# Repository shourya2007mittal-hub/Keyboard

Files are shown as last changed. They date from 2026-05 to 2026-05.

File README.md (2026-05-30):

# KEYBOARD
So I am making an 60% layout keyboard with 2 rotor encoders .So In total there will be 61 Keys and 2 rotor encoders for volume and britness controle but there aren't that many gpios in any devboard therefore I would be using keyboard matrix and diodes to restrict gosting and I choosed Raspberry Pico as controller because it supports KMK and have enought Gpios as well.I also added stabalizers for any keys whose size is over 1.75U
## Features

- Base on Raspberry pico
- Has 61 keys ( 60% Keyboard Matrix)
- Has 2 Rotor Encoder
  ### Schematic
  br>

  ###  PCB Design
<br>


### 3D Design



- ## Bill of Materials (BOM)

| # | Item | Description | Quantity | Unit Price (USD) | Total (USD) | Link |
|---|---|---|---|---|---|---|
| 1 | 80Retros x HMX Volume | Mechanical switches (pack of 35) | 2 packs | 17.8 | 35.6 | https://stackskb.com/store/hmx-volume-0-pack-of-35/ |
| 2 | 1N4148 Diode | DO-35 switching diode | 61 | 0 | 0 | | Already have
| 3 | Raspberry Pi Pico H | RP2040 microcontroller board | 1 | 5.5 | 5.5 | https://robu.in/product/raspberry-pi-pico-with-headers/ |
| 4 |  Keycap Set | Full keycap set | 1 | 26.2 | 26.2 | https://stackskb.com/store/blue-and-blue-double-shot-abs-cherry-profile-keycaps-pre-order/
| 5 | Screw-In Stabilizers V2 | Keyboard stabilizers | 1 | 0 |0 | Already have |
| 6 | PCB  + Shipping | PCB fabrication (JLCPCB) | 1 |31.55| 31.55 | https://jlcpcb.com |

**Estimated Total Hardware Cost:** **USD 98.85**

## Hardware
- Raspberry Pico 
- Cherry MX compatible Switches
- Diode
- 2 layer PCB
- 2 Rotor Encoder

## Firmware
- It is Based on KMK and Circuit Python

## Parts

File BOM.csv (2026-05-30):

Index | Quantity | Part Number | Manufacturer Part Number | Description | Available | Unit Price | Extended Price USD | Link
1 | 2 (pack of 35) | 1644-MX2A-HC1B-ND | 80Retros x HMX Volume |  | 2 | 17.8 | 35.6 | https://stackskb.com/store/hmx-volume-0-pack-of-35/
2 | 61 | 1N4148FSCT-ND | 1N4148TR | DIODE STANDARD 100V 200MA DO35 | Already have | 0 | 0
3 | 1 | 2648-SC0917-ND | SC0917 | Raspberry Pi Pico H RP2040 | 1 | 5.5 | 5.5 | https://robu.in/product/raspberry-pi-pico-with-headers/
4 | 1 | Keycaps Set |  | Keycap Set |  | 26.2 | 26.2 | https://stackskb.com/store/blue-and-blue-double-shot-abs-cherry-profile-keycaps-pre-order/
5 | 1 | Stabilizer |  | 0Already Have |  | 0 | 0
6 | 1 | PCB + 3D Case + Shipping | JLCPCB | PCB fabrication and shipping |  | 31.55 | 31.55 | https://jlcpcb.com

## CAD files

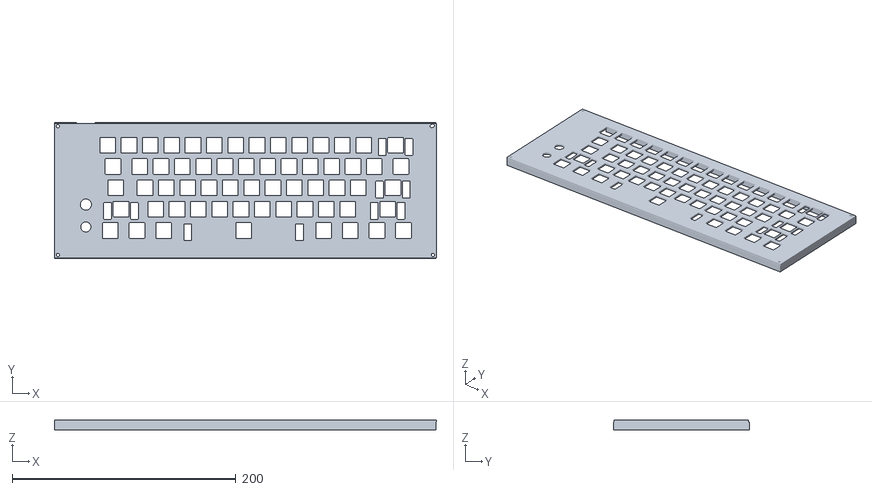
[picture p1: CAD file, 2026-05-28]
Production/UpCase.stl
341.2 x 121.1 x 9.00

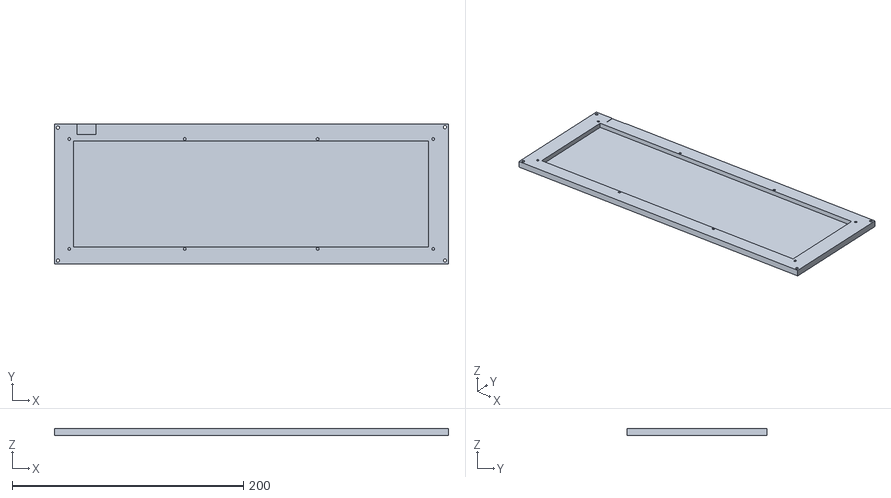
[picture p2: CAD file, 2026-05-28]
Production/LowCover.stl
341.0 x 121.0 x 6.20

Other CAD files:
CAD/Keyboard().f3d

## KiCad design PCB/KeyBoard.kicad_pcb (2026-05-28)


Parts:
A1: RaspberryPi_Pico; RaspberryPi_Pico_Common_Unspecified
D1, D2, D3, D4, D5, D6, D7, D8, D9, D10, D11, D12, D13, D14, D15, D16, D17, D18, D19, D20, D21, D22, D23, D24, D25, D26, D27, D28, D29, D30, D31, D32, D33, D34, D35, D36, D37, D38, D39, D40, D41, D42, D43, D44, D45, D46, D47, D48, D49, D50, D51, D52, D53, D54, D55, D56, D57, D58, D59, D60, D61: 1N4148; D_DO-35_SOD27_P7.62mm_Horizontal
S1: MX_stab; STAB_MX_2u
S2, S3: MX_stab; STAB_MX_2.25u
S4: MX_stab; STAB_MX_2.75u
S5: MX_stab; STAB_MX_6.25u
SW1, SW2, SW3, SW4, SW5, SW6, SW7, SW8, SW9, SW10, SW11, SW12, SW13, SW16, SW17, SW18, SW19, SW20, SW21, SW22, SW23, SW24, SW25, SW26, SW27, SW30, SW31, SW32, SW33, SW34, SW35, SW36, SW37, SW38, SW39, SW40, SW51, SW52, SW53, SW54, SW55, SW56, SW57, SW58, SW59, SW60: SW_Push; SW_Cherry_MX_1.00u_PCB
SW14: SW_Push; SW_Cherry_MX_2.00u_PCB
SW15: SW_Push; SW_Cherry_MX_1.50u_PCB
SW28: SW_Push; SW_Cherry_MX_1.50u_Plate
SW29: SW_Push; SW_Cherry_MX_1.75u_PCB
SW41, SW50: SW_Push; SW_Cherry_MX_2.25u_PCB
SW42, SW43, SW44, SW46, SW48, SW49: SW_Push; SW_Cherry_MX_1.25u_PCB
SW45: SW_Push; SW_Cherry_MX_6.25u_PCB
SW47: SW_Push; SW_Cherry_MX_1.25u_Plate
SW61: SW_Push; SW_Cherry_MX_2.75u_PCB
SW62, SW63: RotaryEncoder_Switch_MP; RotaryEncoder_Alps_EC11E-Switch_Vertical_H20mm

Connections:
A1: A1.27 (GPIO21), SW62.A
A2: A1.32 (GPIO27_ADC1), SW63.A
B1: A1.29 (GPIO22), SW62.B
B2: A1.34 (GPIO28_ADC2), SW63.B
C0: A1.10 (GPIO7), SW1.1, SW15.1, SW29.1, SW42.1, SW50.1
C1: A1.11 (GPIO8), SW2.1, SW16.1, SW30.1, SW43.1, SW51.1
C2: A1.12 (GPIO9), SW3.1, SW17.1, SW31.1, SW44.1, SW52.1
C3: A1.14 (GPIO10), SW4.1, SW18.1, SW32.1, SW53.1
C4: A1.15 (GPIO11), SW5.1, SW19.1, SW33.1, SW54.1
C5: A1.16 (GPIO12), SW6.1, SW20.1, SW34.1, SW45.1, SW55.1
C6: A1.17 (GPIO13), SW7.1, SW21.1, SW35.1, SW56.1
C7: A1.19 (GPIO14), SW8.1, SW22.1, SW36.1, SW57.1
C8: A1.20 (GPIO15), SW9.1, SW23.1, SW37.1, SW46.1, SW58.1
C9: A1.21 (GPIO16), SW10.1, SW24.1, SW38.1, SW47.1, SW59.1
C10: A1.22 (GPIO17), SW11.1, SW25.1, SW39.1, SW48.1, SW60.1
C11: A1.24 (GPIO18), SW12.1, SW26.1, SW40.1, SW49.1, SW61.1
C12: A1.25 (GPIO19), SW13.1, SW27.1, SW41.1
C13: A1.26 (GPIO20), SW14.1, SW28.1
GND: A1.33 (AGND), SW62.C, SW62.S2, SW63.C, SW63.S2
unnamed: A1.3 (GND), A1.8 (GND), A1.13 (GND), A1.18 (GND), A1.23 (GND), A1.28 (GND), A1.38 (GND)
unnamed: D1.2 (A), SW1.2
unnamed: D2.2 (A), SW2.2
unnamed: D3.2 (A), SW3.2
unnamed: D4.2 (A), SW4.2
unnamed: D5.2 (A), SW5.2
unnamed: D6.2 (A), SW6.2
unnamed: D7.2 (A), SW7.2
unnamed: D8.2 (A), SW8.2
unnamed: D9.2 (A), SW9.2
unnamed: D10.2 (A), SW10.2
unnamed: D11.2 (A), SW11.2
unnamed: D12.2 (A), SW12.2
unnamed: D13.2 (A), SW13.2
unnamed: D14.2 (A), SW14.2
unnamed: D15.2 (A), SW15.2
unnamed: D16.2 (A), SW16.2
unnamed: D17.2 (A), SW17.2
unnamed: D18.2 (A), SW18.2
unnamed: D19.2 (A), SW19.2
unnamed: D20.2 (A), SW20.2
unnamed: D21.2 (A), SW21.2
unnamed: D22.2 (A), SW22.2
unnamed: D23.2 (A), SW23.2
unnamed: D24.2 (A), SW24.2
unnamed: D25.2 (A), SW25.2
unnamed: D26.2 (A), SW26.2
unnamed: D27.2 (A), SW27.2
unnamed: D28.2 (A), SW28.2
unnamed: D29.2 (A), SW29.2
unnamed: D30.2 (A), SW30.2
unnamed: D31.2 (A), SW31.2
unnamed: D32.2 (A), SW32.2
unnamed: D33.2 (A), SW33.2
unnamed: D34.2 (A), SW34.2
unnamed: D35.2 (A), SW35.2
unnamed: D36.2 (A), SW36.2
unnamed: D37.2 (A), SW37.2
unnamed: D38.2 (A), SW38.2
unnamed: D39.2 (A), SW39.2
unnamed: D40.2 (A), SW40.2
unnamed: D41.2 (A), SW41.2
unnamed: D42.2 (A), SW42.2
unnamed: D43.2 (A), SW43.2
unnamed: D44.2 (A), SW44.2
unnamed: D45.2 (A), SW45.2
unnamed: D46.2 (A), SW46.2
unnamed: D47.2 (A), SW47.2
unnamed: D48.2 (A), SW48.2
unnamed: D49.2 (A), SW49.2
unnamed: D50.2 (A), SW50.2
unnamed: D51.2 (A), SW51.2
unnamed: D52.2 (A), SW52.2
unnamed: D53.2 (A), SW53.2
unnamed: D54.2 (A), SW54.2
unnamed: D55.2 (A), SW55.2
unnamed: D56.2 (A), SW56.2
unnamed: D57.2 (A), SW57.2
unnamed: D58.2 (A), SW58.2
unnamed: D59.2 (A), SW59.2
unnamed: D60.2 (A), SW60.2
unnamed: D61.2 (A), SW61.2
R0: A1.4 (GPIO2), D1.1 (K), D2.1 (K), D3.1 (K), D4.1 (K), D5.1 (K), D6.1 (K), D7.1 (K), D8.1 (K), D9.1 (K), D10.1 (K), D11.1 (K), D12.1 (K), D13.1 (K), D14.1 (K)
R1: A1.5 (GPIO3), D15.1 (K), D16.1 (K), D17.1 (K), D18.1 (K), D19.1 (K), D20.1 (K), D21.1 (K), D22.1 (K), D23.1 (K), D24.1 (K), D25.1 (K), D26.1 (K), D27.1 (K), D28.1 (K)
R2: A1.6 (GPIO4), D29.1 (K), D30.1 (K), D31.1 (K), D32.1 (K), D33.1 (K), D34.1 (K), D35.1 (K), D36.1 (K), D37.1 (K), D38.1 (K), D39.1 (K), D40.1 (K), D41.1 (K)
R3: A1.7 (GPIO5), D50.1 (K), D51.1 (K), D52.1 (K), D53.1 (K), D54.1 (K), D55.1 (K), D56.1 (K), D57.1 (K), D58.1 (K), D59.1 (K), D60.1 (K), D61.1 (K)
R4: A1.9 (GPIO6), D42.1 (K), D43.1 (K), D44.1 (K), D45.1 (K), D46.1 (K), D47.1 (K), D48.1 (K), D49.1 (K)
S1: A1.31 (GPIO26_ADC0), SW62.S1
S2: A1.2 (GPIO1), SW63.S1



Board: 2 copper layers, 321.0 x 101.0 mm, 130 parts (61 on the bottom side), 88 nets.

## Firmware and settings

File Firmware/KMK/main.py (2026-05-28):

import board
import digitalio
import usb_hid
import rotaryio
from adafruit_hid.keyboard import Keyboard
from adafruit_hid.keycode import Keycode
from adafruit_hid.consumer_control import ConsumerControl
from adafruit_hid.consumer_control_code import ConsumerControlCode
import time

kbd = Keyboard(usb_hid.devices)
cc = ConsumerControl(usb_hid.devices)

# =========================
# MATRIX SETUP
# =========================

ROW_PINS = [board.GP2, board.GP3, board.GP4, board.GP5, board.GP6]
COL_PINS = [
    board.GP7, board.GP8, board.GP9, board.GP10,
    board.GP11, board.GP12, board.GP13,
    board.GP14, board.GP15, board.GP16,
    board.GP17, board.GP18, board.GP19, board.GP20
]

rows = []
cols = []

for pin in ROW_PINS:
    r = digitalio.DigitalInOut(pin)
    r.direction = digitalio.Direction.OUTPUT
    r.value = True
    rows.append(r)

for pin in COL_PINS:
    c = digitalio.DigitalInOut(pin)
    c.direction = digitalio.Direction.INPUT
    c.pull = digitalio.Pull.UP
    cols.append(c)

# Example 60% partial keymap (edit fully yourself)
keymap = [
    [Keycode.ESCAPE, Keycode.ONE, Keycode.TWO, Keycode.THREE, Keycode.FOUR,
     Keycode.FIVE, Keycode.SIX, Keycode.SEVEN, Keycode.EIGHT,
     Keycode.NINE, Keycode.ZERO, Keycode.MINUS,
     Keycode.EQUALS, Keycode.BACKSPACE],

    [Keycode.TAB, Keycode.Q, Keycode.W, Keycode.E, Keycode.R,
     Keycode.T, Keycode.Y, Keycode.U, Keycode.I,
     Keycode.O, Keycode.P, Keycode.LEFT_BRACKET,
     Keycode.RIGHT_BRACKET, Keycode.BACKSLASH],

    [Keycode.CAPS_LOCK, Keycode.A, Keycode.S, Keycode.D, Keycode.F,
     Keycode.G, Keycode.H, Keycode.J, Keycode.K,
     Keycode.L, Keycode.SEMICOLON, Keycode.QUOTE,
     Keycode.ENTER, None],

    [Keycode.LEFT_SHIFT, Keycode.Z, Keycode.X, Keycode.C, Keycode.V,
     Keycode.B, Keycode.N, Keycode.M, Keycode.COMMA,
     Keycode.PERIOD, Keycode.FORWARD_SLASH,
     Keycode.RIGHT_SHIFT, None, None],

    [Keycode.LEFT_CONTROL, Keycode.LEFT_GUI,
     Keycode.LEFT_ALT, None, None, None,
     Keycode.SPACE, None, None,
     Keycode.RIGHT_ALT, Keycode.FN,
     Keycode.RIGHT_CONTROL, None, None]
]

pressed_keys = set()

# =========================
# ROTARY ENCODERS
# =========================

# Encoder 1 (Volume)
encoder1 = rotaryio.IncrementalEncoder(board.GP26, board.GP27)
last_pos1 = encoder1.position

# Encoder 2 (Brightness)
encoder2 = rotaryio.IncrementalEncoder(board.GP28, board.GP21)
last_pos2 = encoder2.position

# Encoder buttons
enc1_btn = digitalio.DigitalInOut(board.GP22)
enc1_btn.direction = digitalio.Direction.INPUT
enc1_btn.pull = digitalio.Pull.UP

enc2_btn = digitalio.DigitalInOut(board.GP1)
enc2_btn.direction = digitalio.Direction.INPUT
enc2_btn.pull = digitalio.Pull.UP

# =========================
# MAIN LOOP
# =========================

while True:

    # ----- MATRIX SCAN -----
    for r_idx, row in enumerate(rows):
        row.value = False

        for c_idx, col in enumerate(cols):
            if not col.value:
                key = keymap[r_idx][c_idx]
                if key and key not in pressed_keys:
                    kbd.press(key)
                    pressed_keys.add(key)
            else:
                key = keymap[r_idx][c_idx]
                if key and key in pressed_keys:
                    kbd.release(key)
                    pressed_keys.remove(key)

        row.value = True

    # ----- ENCODER 1 (Volume) -----
    pos1 = encoder1.position
    if pos1 > last_pos1:
        cc.send(ConsumerControlCode.VOLUME_INCREMENT)
    elif pos1 < last_pos1:
        cc.send(ConsumerControlCode.VOLUME_DECREMENT)
    last_pos1 = pos1

    # ----- ENCODER 2 (Brightness) -----
    pos2 = encoder2.position
    if pos2 > last_pos2:
        cc.send(ConsumerControlCode.BRIGHTNESS_INCREMENT)
    elif pos2 < last_pos2:
        cc.send(ConsumerControlCode.BRIGHTNESS_DECREMENT)
    last_pos2 = pos2

    # ----- Encoder Buttons -----
    if not enc1_btn.value:
        # Screenshot (Win+Shift+S)
        kbd.press(Keycode.LEFT_GUI, Keycode.LEFT_SHIFT, Keycode.S)
        time.sleep(0.1)
        kbd.release_all()

    if not enc2_btn.value:
        # Delete
        kbd.send(Keycode.DELETE)

    time.sleep(0.01)

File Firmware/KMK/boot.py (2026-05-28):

import board
import digitalio
import storage
import usb_cdc
import usb_hid
import time

# ---- SET YOUR ROW PINS HERE ----
ROW_PINS = [
    board.GP2,
    board.GP3,
    board.GP4,
    board.GP5,
    board.GP6
]

pressed = False
rows = []

for pin in ROW_PINS:
    row = digitalio.DigitalInOut(pin)
    row.direction = digitalio.Direction.INPUT
    row.pull = digitalio.Pull.UP
    rows.append(row)

time.sleep(0.1)

for row in rows:
    if not row.value:   # LOW = key pressed
        pressed = True
        break

if not pressed:
    # Normal keyboard mode
    storage.disable_usb_drive()
    usb_cdc.disable()
